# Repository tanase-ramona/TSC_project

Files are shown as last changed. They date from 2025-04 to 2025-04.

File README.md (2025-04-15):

## EBookReader

Am început realizarea proiectului pornind de la schema electrică oferită în enunț. Am adăugat fiecare componentă din biblioteca sugerata și le-am conectat corespunzător, atribuindu-le etichete adecvate. După finalizarea conexiunilor, am rulat o verificare ERC pentru a identifica eventualele erori si am rezolvat marea majoritate. A rămas o singură eroare nerezolvată, deoarece Fusion nu a putut indica locația acesteia. După ce schema a fost finalizată, am trecut la partea de PCB. Am decupat placa conform dimensiunilor cerute folosind masuratorile oferite de Fusion. Cea mai mare provocare a fost identificarea și poziționarea corectă a componentelor pe PGB. După plasare, am realizat rutarea și am validat designul în funcție de regulile specificate în enunț. Pentru a elimina erorile, a fost necesară modificarea footprint-ului pentru anumite piese. În final, am realizat planul de masă atât pentru stratul superior, cât și pentru cel inferior.

## Arhitectură Generală a Sistemului

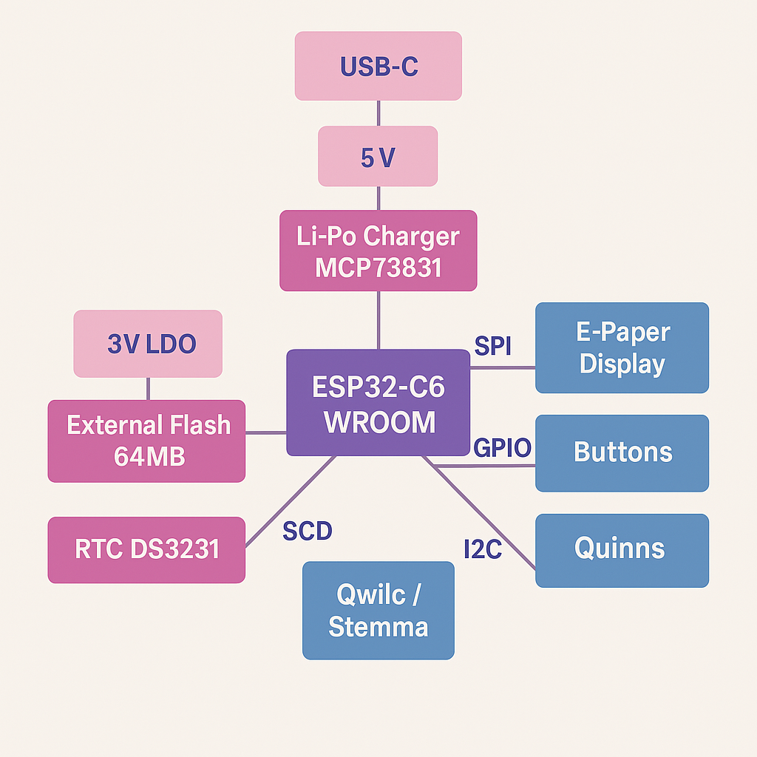
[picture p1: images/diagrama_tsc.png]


## Descriere Generală

Modulul **ESP32-C6-WROOM-1-N8** este nucleul sistemului, facilitând comunicarea cu toate celelalte periferice prin interfețe standard precum I2C, SPI și GPIO. Alimentarea este realizată printr-o baterie Li-Po, gestionată de un controler de încărcare dedicat și monitorizată constant cu ajutorul unui fuel gauge.

## Componente Hardware

###  ESP32-C6
- Microcontroller cu procesor RISC-V
- Conectivitate Wi-Fi 6 și Bluetooth LE
- Interfețe: SPI, I2C, UART, GPIO
- Tensiune de operare: 3.3V

### Componente și resurse

| Componentă  | Link Achiziție | Datasheet |
|---|---|---|
| BOOT_BUTTON | https://ro.mouser.com/ProductDetail/Panasonic/EVQ-P7L01P | https://componentsearchengine.com/Datasheets/2/EVQP7L01P.pdf |
| C1 | https://ro.mouser.com/ProductDetail/YAGEO/CC0402MRX5R5BB106 | https://componentsearchengine.com/Datasheets/2/CC0402MRX5R5BB106.pdf |
| C1_BAT | https://ro.mouser.com/ProductDetail/YAGEO/CC0402MRX5R5BB106 | https://componentsearchengine.com/Datasheets/2/CC0402MRX5R5BB106.pdf |
| C2 | https://ro.mouser.com/ProductDetail/YAGEO/CC0402MRX5R5BB106 | https://componentsearchengine.com/Datasheets/2/CC0402MRX5R5BB106.pdf |
| C2_BAT | https://ro.mouser.com/ProductDetail/YAGEO/CC0402MRX5R5BB106 | https://componentsearchengine.com/Datasheets/2/CC0402MRX5R5BB106.pdf |
| C3 | https://ro.mouser.com/ProductDetail/YAGEO/CC0402MRX5R5BB106 | https://componentsearchengine.com/Datasheets/2/CC0402MRX5R5BB106.pdf |
| C4 | https://ro.mouser.com/ProductDetail/YAGEO/CC0402MRX5R5BB106 | https://componentsearchengine.com/Datasheets/2/CC0402MRX5R5BB106.pdf |
| C4_USB | https://ro.mouser.com/ProductDetail/YAGEO/CC0402MRX5R5BB106 | https://componentsearchengine.com/Datasheets/2/CC0402MRX5R5BB106.pdf |
| C5 | https://ro.mouser.com/ProductDetail/YAGEO/CC0402MRX5R5BB106 | https://componentsearchengine.com/Datasheets/2/CC0402MRX5R5BB106.pdf |
| C5_USB | https://ro.mouser.com/ProductDetail/YAGEO/CC0402MRX5R5BB106 | https://componentsearchengine.com/Datasheets/2/CC0402MRX5R5BB106.pdf |
| C6 | https://ro.mouser.com/ProductDetail/YAGEO/CC0402MRX5R5BB106 | https://componentsearchengine.com/Datasheets/2/CC0402MRX5R5BB106.pdf |
| C7 | https://ro.mouser.com/ProductDetail/YAGEO/CC0402MRX5R5BB106 | https://componentsearchengine.com/Datasheets/2/CC0402MRX5R5BB106.pdf |
| C8 | https://ro.mouser.com/ProductDetail/YAGEO/CC0402MRX5R5BB106 | https://componentsearchengine.com/Datasheets/2/CC0402MRX5R5BB106.pdf |
| C9 | https://ro.mouser.com/ProductDetail/YAGEO/CC0402MRX5R5BB106 | https://componentsearchengine.com/Datasheets/2/CC0402MRX5R5BB106.pdf |
| C10 | https://ro.mouser.com/ProductDetail/YAGEO/CC0402MRX5R5BB106 | https://componentsearchengine.com/Datasheets/2/CC0402MRX5R5BB106.pdf |
| D1 | https://ro.mouser.com/ProductDetail/STMicroelectronics/STPS2L30A | https://www.st.com/resource/en/datasheet/stps2l30.pdf |
| D2 | https://ro.mouser.com/ProductDetail/STMicroelectronics/STPS2L30A | https://www.st.com/resource/en/datasheet/stps2l30.pdf |
| D3 | https://ro.mouser.com/ProductDetail/STMicroelectronics/STPS2L30A | https://www.st.com/resource/en/datasheet/stps2l30.pdf |
| D4 | https://ro.mouser.com/ProductDetail/STMicroelectronics/STPS2L30A | https://www.st.com/resource/en/datasheet/stps2l30.pdf |
| IC1 | https://ro.mouser.com/ProductDetail/Texas-Instruments/BQ24075RGTT | https://www.ti.com/lit/ds/symlink/bq24075.pdf |
| Q1 | https://ro.mouser.com/ProductDetail/Diodes-Incorporated/DMG2305UX-7 | https://www.diodes.com/assets/Datasheets/ds31771.pdf |
| Q2 | https://ro.mouser.com/ProductDetail/Diodes-Incorporated/DMG2305UX-7 | https://www.diodes.com/assets/Datasheets/ds31771.pdf |
| Q3 | https://ro.mouser.com/ProductDetail/Diodes-Incorporated/DMG2305UX-7 | https://www.diodes.com/assets/Datasheets/ds31771.pdf |
| Q4 | https://ro.mouser.com/ProductDetail/Diodes-Incorporated/DMG2305UX-7 | https://www.diodes.com/assets/Datasheets/ds31771.pdf |
| R1 | https://ro.mouser.com/ProductDetail/YAGEO/RC0402FR-0710KL | https://componentsearchengine.com/Datasheets/2/RC0402FR-0710KL.pdf |
| R2 | https://ro.mouser.com/ProductDetail/YAGEO/RC0402FR-0710KL | https://componentsearchengine.com/Datasheets/2/RC0402FR-0710KL.pdf |
| R3 | https://ro.mouser.com/ProductDetail/YAGEO/RC0402FR-0710KL | https://componentsearchengine.com/Datasheets/2/RC0402FR-0710KL.pdf |
| R4 | https://ro.mouser.com/ProductDetail/YAGEO/RC0402FR-0710KL | https://componentsearchengine.com/Datasheets/2/RC0402FR-0710KL.pdf |
| R5 | https://ro.mouser.com/ProductDetail/YAGEO/RC0402FR-07100KL | https://ro.mouser.com/datasheet/2/447/YAGEO_PYu_RC_Group_51_RoHS_L_12-3313492.pdf |
| R6 | https://ro.mouser.com/ProductDetail/YAGEO/RC0402FR-07100KL | https://ro.mouser.com/datasheet/2/447/YAGEO_PYu_RC_Group_51_RoHS_L_12-3313492.pdf |
| R7 | https://ro.mouser.com/ProductDetail/YAGEO/RC0402FR-07100KL | https://ro.mouser.com/datasheet/2/447/YAGEO_PYu_RC_Group_51_RoHS_L_12-3313492.pdf |
| R8 | https://ro.mouser.com/ProductDetail/YAGEO/RC0402FR-07100KL | https://ro.mouser.com/datasheet/2/447/YAGEO_PYu_RC_Group_51_RoHS_L_12-3313492.pdf |
| R9 | https://ro.mouser.com/ProductDetail/YAGEO/RC0402FR-07100KL | https://ro.mouser.com/datasheet/2/447/YAGEO_PYu_RC_Group_51_RoHS_L_12-3313492.pdf |
| R10 | https://ro.mouser.com/ProductDetail/YAGEO/RC0402FR-07100KL | https://ro.mouser.com/datasheet/2/447/YAGEO_PYu_RC_Group_51_RoHS_L_12-3313492.pdf |
| RESET_BUTTON | https://ro.mouser.com/ProductDetail/Panasonic/EVQ-P7L01P | https://componentsearchengine.com/Datasheets/2/EVQP7L01P.pdf |
| R_BOOT | https://ro.mouser.com/ProductDetail/YAGEO/RC0402FR-07100KL | https://ro.mouser.com/datasheet/2/447/YAGEO_PYu_RC_Group_51_RoHS_L_12-3313492.pdf |
| R_CAPACITOR  | https://ro.mouser.com/ProductDetail/YAGEO/RC0402FR-07100KL | https://ro.mouser.com/datasheet/2/447/YAGEO_PYu_RC_Group_51_RoHS_L_12-3313492.pdf |
| R_CHANGE | https://ro.mouser.com/ProductDetail/YAGEO/RC0402FR-07100KL | https://ro.mouser.com/datasheet/2/447/YAGEO_PYu_RC_Group_51_RoHS_L_12-3313492.pdf |
| R_CL1 | https://ro.mouser.com/ProductDetail/YAGEO/RC0402FR-07100KL | https://ro.mouser.com/datasheet/2/447/YAGEO_PYu_RC_Group_51_RoHS_L_12-3313492.pdf |
| R_RESET | https://ro.mouser.com/ProductDetail/YAGEO/RC0402FR-07100KL | https://ro.mouser.com/datasheet/2/447/YAGEO_PYu_RC_Group_51_RoHS_L_12-3313492.pdf |
| SENSOR2 | https://ro.mouser.com/ProductDetail/Bosch-Sensortec/BME680 | https://ro.mouser.com/datasheet/2/783/BST_BME680_DS001-1509608.pdf |
| SJ1 | https://grabcad.com/library/solder-jumpers-1 | https://grabcad.com/library/solder-jumpers-1 |
| U1 | https://ro.mouser.com/ProductDetail/Winbond/W25Q512JVEIQ | https://ro.mouser.com/datasheet/2/949/Winbond_W25Q512JV_Datasheet-3240039.pdf |
| U2 | https://ro.mouser.com/ProductDetail/Espressif-Systems/ESP32-C6-WROOM-1-N8 | https://ro.mouser.com/datasheet/2/891/Espressif_ESP32_C6_WROOM_1__Datasheet_V0_1_PRELIMI-3239987.pdf |
| U3 | https://ro.mouser.com/ProductDetail/Analog-Devices-Maxim-Integrated/DS3231SN | https://ro.mouser.com/datasheet/2/609/DS3231-3421123.pdf |
| U4 | https://ro.mouser.com/ProductDetail/Analog-Devices-Maxim-Integrated/MAX17048G+T10 | https://ro.mouser.com/datasheet/2/609/MAX17048_MAX17049-3469099.pdf |
| U5 | https://ro.mouser.com/ProductDetail/Microchip-Technology/MCP73831T-2ACI-OT | https://ro.mouser.com/datasheet/2/268/MCP73831_Family_Data_Sheet_DS20001984H-3441711.pdf |

###  Sistem de Alimentare
- **MCP73831** – controler de încărcare pentru baterii LiPo
- **MAX17048** – fuel gauge pentru măsurarea nivelului de baterie și avertizare
- **XC6220A331MR** – stabilizator de tensiune 3.3V LDO

###  Protecție și Conectivitate
- Protecție ESD pentru liniile USB (USBLC6)
- Diode Schottky pentru protecție la supratensiune
- Conector USB-C pentru alimentare și comunicație serială

###  Interfață Utilizator
- Buton RESET pentru restart manual
- LED pentru indicarea stării de încărcare

## Estimare Totală Consum în Funcționare Activă:
**~120 – 200 mA** (fără SD Card)

## Estimare Totală în Modul Sleep:
**< 100 µA** (cu ESP32 în deep sleep și periferice oprite)

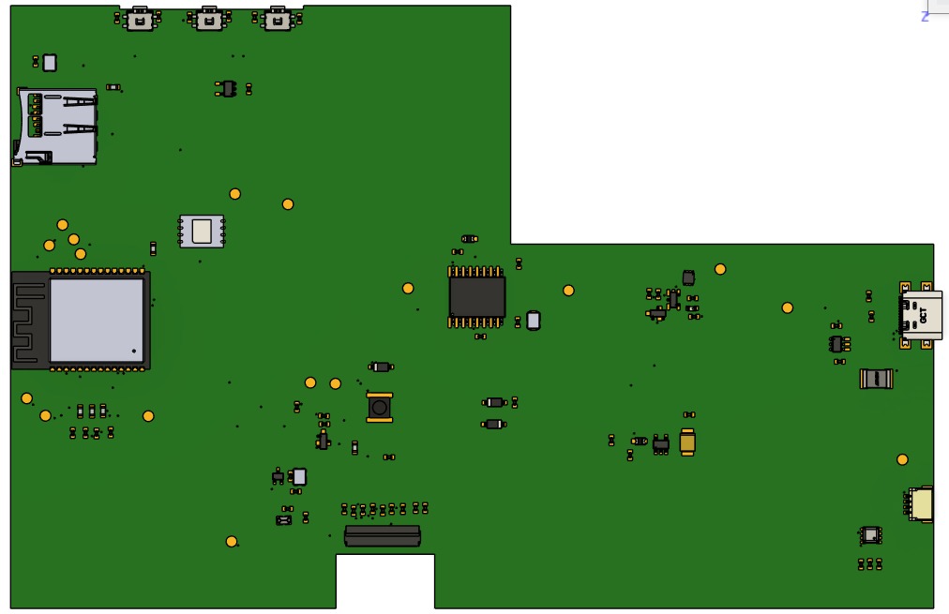
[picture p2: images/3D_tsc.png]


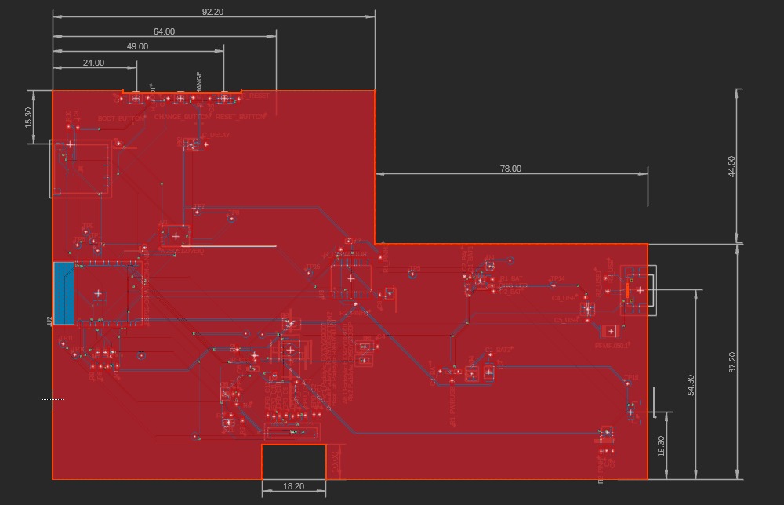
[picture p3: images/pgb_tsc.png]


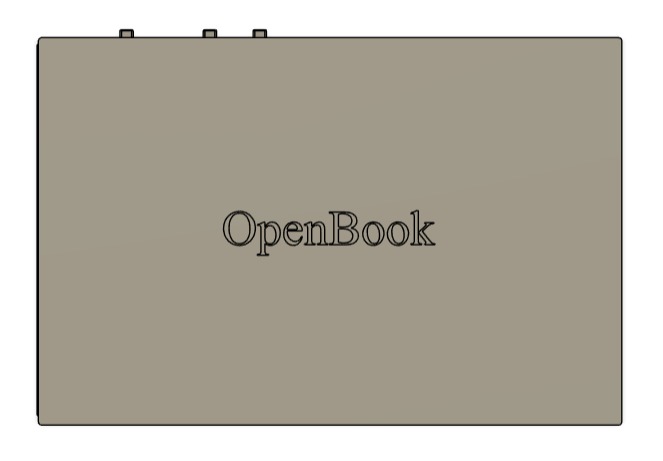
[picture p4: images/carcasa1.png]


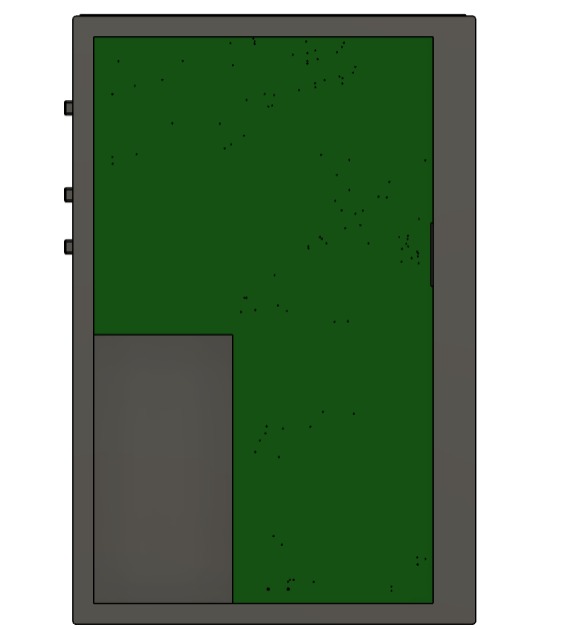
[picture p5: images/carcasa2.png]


---

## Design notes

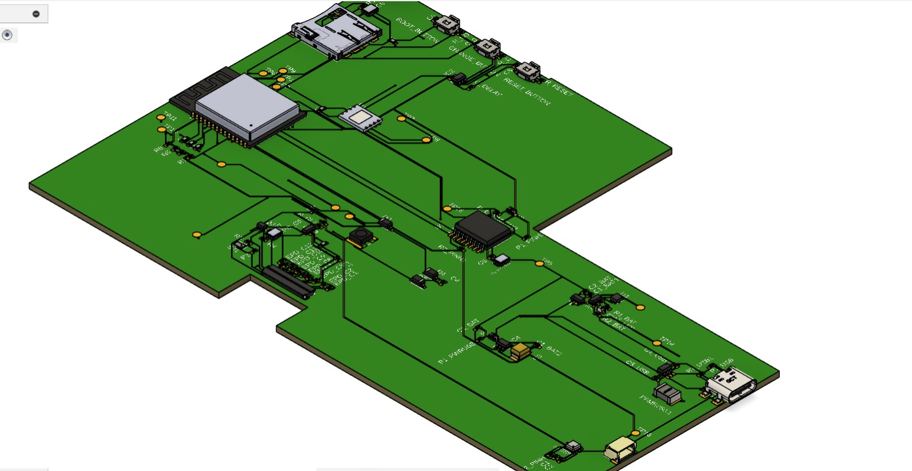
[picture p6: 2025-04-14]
images/3D.png

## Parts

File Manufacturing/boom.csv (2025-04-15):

BOOT_BUTTON | 23.84 | 85.75 | 180.00 | BUTTON_CUSYOMV1 | MYBUTTON
C1 | 158.44 | -15.01 | 270.00 | 100nF | EAGLE-LTSPICE_C0402
C10 | 33.02 | 85.79 | 270.00 | 100nF | EAGLE-LTSPICE_C0402
C10_SUPERCAP | 96.40 | 29.90 | 270.00 | CPH3225A | CAPCP3225X100N
C1_BAT | 110.79 | 7.83 | 270.00 | 4.7uF | EAGLE-LTSPICE_C0402
C1_BAT1 | 119.41 | 34.73 | 90.00 | 4.7uF | EAGLE-LTSPICE_C0402
C1_BAT2 | 125.15 | 12.53 | 180.00 | 4.7uF | EAGLE-LTSPICE_C0402
C2 | 160.12 | -15.04 | 270.00 | 100nF | EAGLE-LTSPICE_C0402
C2_BAT | 117.73 | 34.83 | 88.30 | 4.7uF | EAGLE-LTSPICE_C0402
C3 | 124.82 | 7.45 | 270.00 | 100uF TANT | RCL_CT3528
C4 | 92.95 | 14.79 | 270.00 | 4.7uF/25V | EAGLE-LTSPICE_C0402
C4_USB | 152.27 | 28.91 | 180.00 | 100nF | EAGLE-LTSPICE_C0402
C5 | 45.02 | 85.82 | 270.00 | 1uF | EAGLE-LTSPICE_C0402
C5_USB | 152.88 | 22.31 | 180.00 | 4.7uF | EAGLE-LTSPICE_C0402
C6 | 19.64 | 85.69 | 270.00 | 100nF | EAGLE-LTSPICE_C0402
C7 | 69.80 | 4.69 | 0.00 | 10uF | EAGLE-LTSPICE_C0402
C8 | 93.50 | 29.59 | 90.00 | 100nF | EAGLE-LTSPICE_C0402
C9 | 7.18 | 77.49 | 90.00 | 100nF | EAGLE-LTSPICE_C0402
CHANGE_BUTTON | 36.66 | 85.75 | 180.00 | BUTTON_CUSYOMV1 | MYBUTTON
CHG_LED | 125.67 | 32.15 | 270.00 |  | ADAFRUIT_CHIP-LED0603
C_DELAY | 43.93 | 72.57 | 270.00 | 100nF | EAGLE-LTSPICE_C0402
D1 | 152.95 | 25.53 | 0.00 | USBLC6-2SC6Y | SOT95P280X145-6N
D10 | 17.06 | 13.23 | 90.00 | PGB1010603MR | DIOC1608X36N
D11 | 63.48 | 6.43 | 90.00 | PGB1010603MR | DIOC1608X36N
D12 | 26.30 | 43.13 | 90.00 | PGB1010603MR | DIOC1608X36N
D2 | 115.92 | 7.64 | 180.00 | ESP32_WROVER_AVX---SD0805S020S1R0_AVX_SD0805S020S1R0_0_0AVX_SD0805S020S1R0_0_0 | ESP32_WROVER_AVX---SD0805S020S1R0_AVX_SD0805S020S1R0_0
D3 | 68.31 | 21.34 | 0.00 | MBR0530 | SOD3716X135N
D4 | 89.25 | 14.74 | 0.00 | MBR0530 | SOD3716X135N
D5 | 89.09 | 10.74 | 180.00 | MBR0530 | SOD3716X135N
D6 | 12.85 | 13.14 | 90.00 | PGB1010603MR | DIOC1608X36N
D7 | 84.67 | 44.94 | 0.00 | ESP32_WROVER_AVX---SD0805S020S1R0_AVX_SD0805S020S1R0_0_0AVX_SD0805S020S1R0_0_0 | ESP32_WROVER_AVX---SD0805S020S1R0_AVX_SD0805S020S1R0_0
D8 | 15.03 | 13.14 | 90.00 | PGB1010603MR | DIOC1608X36N
D9 | 18.94 | 72.93 | 0.00 | PGB1010603MR | DIOC1608X36N
EPD_C1 | 76.43 | -4.67 | 90.00 | 1uF/50V | EAGLE-LTSPICE_C0402
EPD_C10 | 64.95 | -5.05 | 90.00 | 1uF/50V | EAGLE-LTSPICE_C0402
EPD_C11 | 63.25 | -5.19 | 90.00 | 1uF/50V | EAGLE-LTSPICE_C0402
EPD_C12 | 61.54 | -4.89 | 90.00 | 1uF/50V | EAGLE-LTSPICE_C0402
EPD_C2 | 74.69 | -4.67 | 270.00 | 1uF/50V | EAGLE-LTSPICE_C0402
EPD_C5 | 72.33 | -4.85 | 90.00 | 0.1uF/50V | EAGLE-LTSPICE_C0402
EPD_C6 | 53.25 | 1.13 | 90.00 | 1uF/50V | EAGLE-LTSPICE_C0402
EPD_C7 | 70.26 | -4.87 | 90.00 | 1uF/50V | EAGLE-LTSPICE_C0402
EPD_C8 | 68.63 | -5.15 | 90.00 | 1uF/50V | EAGLE-LTSPICE_C0402
EPD_C9 | 66.79 | -4.85 | 90.00 | 1uF/50V | EAGLE-LTSPICE_C0402
FH34SRJ-24S-0.5SH_99_1 | 68.58 | -9.65 | 0.00 | FH34SRJ-24S-0.5SH_99_ | FH34SRJ24S05SH99
IC2 | 39.57 | 72.63 | 180.00 | BD5229G-TR | SOT95P280X125-5N
IC4 | 119.91 | 7.03 | 90.00 | XC6220A331MR-G | SOT95P280X120-5N
J1 | 167.16 | -4.01 | 90.00 | QWIIC_RIGHT_ANGLE | JST04_1MM_RA
J2 | 166.63 | 30.86 | 90.00 | SAMACSYS_PARTS_USB4110-GF-A | SAMACSYS_PARTS_USB4110GFA
J4 | 8.28 | 65.61 | 270.00 | 112A-TAAR-R03_ATTEND | 112ATAARR03ATTEND
L1 | 68.03 | 13.85 | 89.90 | 68uH | IND_4828-WE-TPC_WRE
MCP1 | 122.21 | 33.72 | 180.00 | ESP32_WROVER_SPARKFUN-IC-POWER_MCP73831 | ESP32_WROVER_SPARKFUN-IC-POWER_SOT23-5
PFMF.050.1 | 159.63 | 19.14 | 180.00 | ESP32C6_VARISTORCN1812 | ESP32C6_VARISTOR_CT/CN1812
Q1 | 118.61 | 31.21 | 90.00 | 20V/4.2A/52mΩ/1.4W | ESP32_WROVER_SPARKFUN-DISCRETESEMI_SOT23-3
Q2 | 57.68 | 8.36 | 0.00 | 20V/4.2A/52mΩ/1.4W | ESP32_WROVER_SPARKFUN-DISCRETESEMI_SOT23-3
Q3 | 49.32 | 1.24 | 90.00 | SI1308EDL-T1-GE3 | SOT65P210X110-3N
R1 | 18.47 | 9.27 | 90.00 | 10k | ESP32_WROVER_EAGLE-LTSPICE_R0402
R10 | 4.61 | 77.67 | 90.00 | 10K | ESP32_WROVER_EAGLE-LTSPICE_R0402
R1_BAT | 125.76 | 34.01 | 0.00 | 200 | ESP32_WROVER_EAGLE-LTSPICE_R0402
R1_PINH | 57.76 | 12.31 | 356.70 | 10k | ESP32_WROVER_EAGLE-LTSPICE_R0402
R1_PINH1 | 93.71 | 40.35 | 270.00 | 10k | ESP32_WROVER_EAGLE-LTSPICE_R0402
R1_PWRUSB | 114.22 | 5.07 | 90.00 | 100k | ESP32_WROVER_EAGLE-LTSPICE_R0402
R2 | 54.41 | -6.43 | 90.00 | 2.2 | ESP32_WROVER_EAGLE-LTSPICE_R0402
R2_BAT | 126.02 | 30.61 | 180.00 | 2K | ESP32_WROVER_EAGLE-LTSPICE_R0402
R2_PINH | 156.80 | -15.09 | 270.00 | 10k | ESP32_WROVER_EAGLE-LTSPICE_R0402
R2_PINH1 | 86.65 | 26.95 | 179.60 | 10k | ESP32_WROVER_EAGLE-LTSPICE_R0402
R2_USB | 158.23 | 34.39 | 270.00 | 5k1 | ESP32_WROVER_EAGLE-LTSPICE_R0402
R2_USB1 | 158.72 | 30.63 | 270.00 | 5k1 | ESP32_WROVER_EAGLE-LTSPICE_R0402
R3 | 51.09 | -4.83 | 180.00 | 0.47 | ESP32_WROVER_EAGLE-LTSPICE_R0402
R4 | 52.59 | -1.63 | 180.00 | 10k | ESP32_WROVER_EAGLE-LTSPICE_R0402
R5 | 15.85 | 9.07 | 90.00 | 10K | ESP32_WROVER_EAGLE-LTSPICE_R0402
R6 | 13.83 | 9.17 | 90.00 | 10K | ESP32_WROVER_EAGLE-LTSPICE_R0402
R7 | 51.61 | 1.17 | 90.00 | 10K | ESP32_WROVER_EAGLE-LTSPICE_R0402
R8 | 11.47 | 9.17 | 90.00 | 10K | ESP32_WROVER_EAGLE-LTSPICE_R0402
R9 | 52.79 | 13.97 | 90.00 | 10K | ESP32_WROVER_EAGLE-LTSPICE_R0402
RESET_BUTTON | 49.26 | 85.75 | 180.00 | BUTTON_CUSYOMV1 | MYBUTTON
R_BOOT | 27.29 | 85.95 | 270.00 | 10K | ESP32_WROVER_EAGLE-LTSPICE_R0402
R_CAPACITOR | 82.42 | 42.57 | 0.00 | 15 | ESP32_WROVER_EAGLE-LTSPICE_R0402
R_CHANGE | 40.22 | 85.97 | 270.00 | 10K | ESP32_WROVER_EAGLE-LTSPICE_R0402
R_CL1 | 57.86 | 10.79 | 0.00 | 10k | ESP32_WROVER_EAGLE-LTSPICE_R0402
R_RESET | 53.26 | 85.57 | 270.00 | 10K | ESP32_WROVER_EAGLE-LTSPICE_R0402
SENSOR2 | 158.64 | -9.79 | 180.00 | ESP32_WROVER_BME680_BME680 | ESP32_WROVER_BME680_PSON80P300X300X100-8N
SJ1 | 50.38 | -6.95 | 2.20 |  | SJ
TP1 | 11.66 | 44.87 | 0.00 | TPTP20R | TP20R
TP10 | 6.44 | 12.35 | 0.00 | TPTP20R | TP20R
TP11 | 2.99 | 15.55 | 0.00 | TPTP20R | TP20R
TP12 | 40.74 | -10.85 | 0.00 | TPTP20R | TP20R
TP13 | 55.29 | 18.45 | 0.00 | TPTP20R | TP20R
TP14 | 143.24 | 32.25 | 0.00 | TPTP20R | TP20R
TP15 | 73.29 | 35.85 | 0.00 | TPTP20R | TP20R
TP16 | 164.44 | 4.25 | 0.00 | TPTP20R | TP20R
TP17 | 59.89 | 18.25 | 0.00 | TPTP20R | TP20R
TP2 | 12.91 | 42.17 | 0.00 | TPTP20R | TP20R
TP3 | 130.86 | 39.37 | 0.00 | TPTP20R | TP20R
TP4 | 25.41 | 12.27 | 0.00 | TPTP20R | TP20R
TP5 | 102.89 | 35.45 | 0.00 | TPTP20R | TP20R
TP6 | 7.14 | 43.75 | 0.00 | TPTP20R | TP20R
TP7 | 41.39 | 53.25 | 0.00 | TPTP20R | TP20R
TP8 | 51.14 | 51.35 | 0.00 | TPTP20R | TP20R
TP9 | 9.59 | 47.55 | 0.00 | TPTP20R | TP20R
U1 | 35.22 | 46.36 | 0.00 | W25Q512JVEIQ | SON127P600X800X80-9N
U2 | 16.00 | 30.04 | 90.00 | ESP32-C6-WROOM-1-N8 | XCVR_ESP32-C6-WROOM-1-N8
U3 | 85.39 | 34.22 | 90.00 | DS3231SN# | SOIC127P1032X265-16N
U4 | 125.00 | 37.75 | 267.80 | MAX17048G+T10 | SON50P200X200X80-9N

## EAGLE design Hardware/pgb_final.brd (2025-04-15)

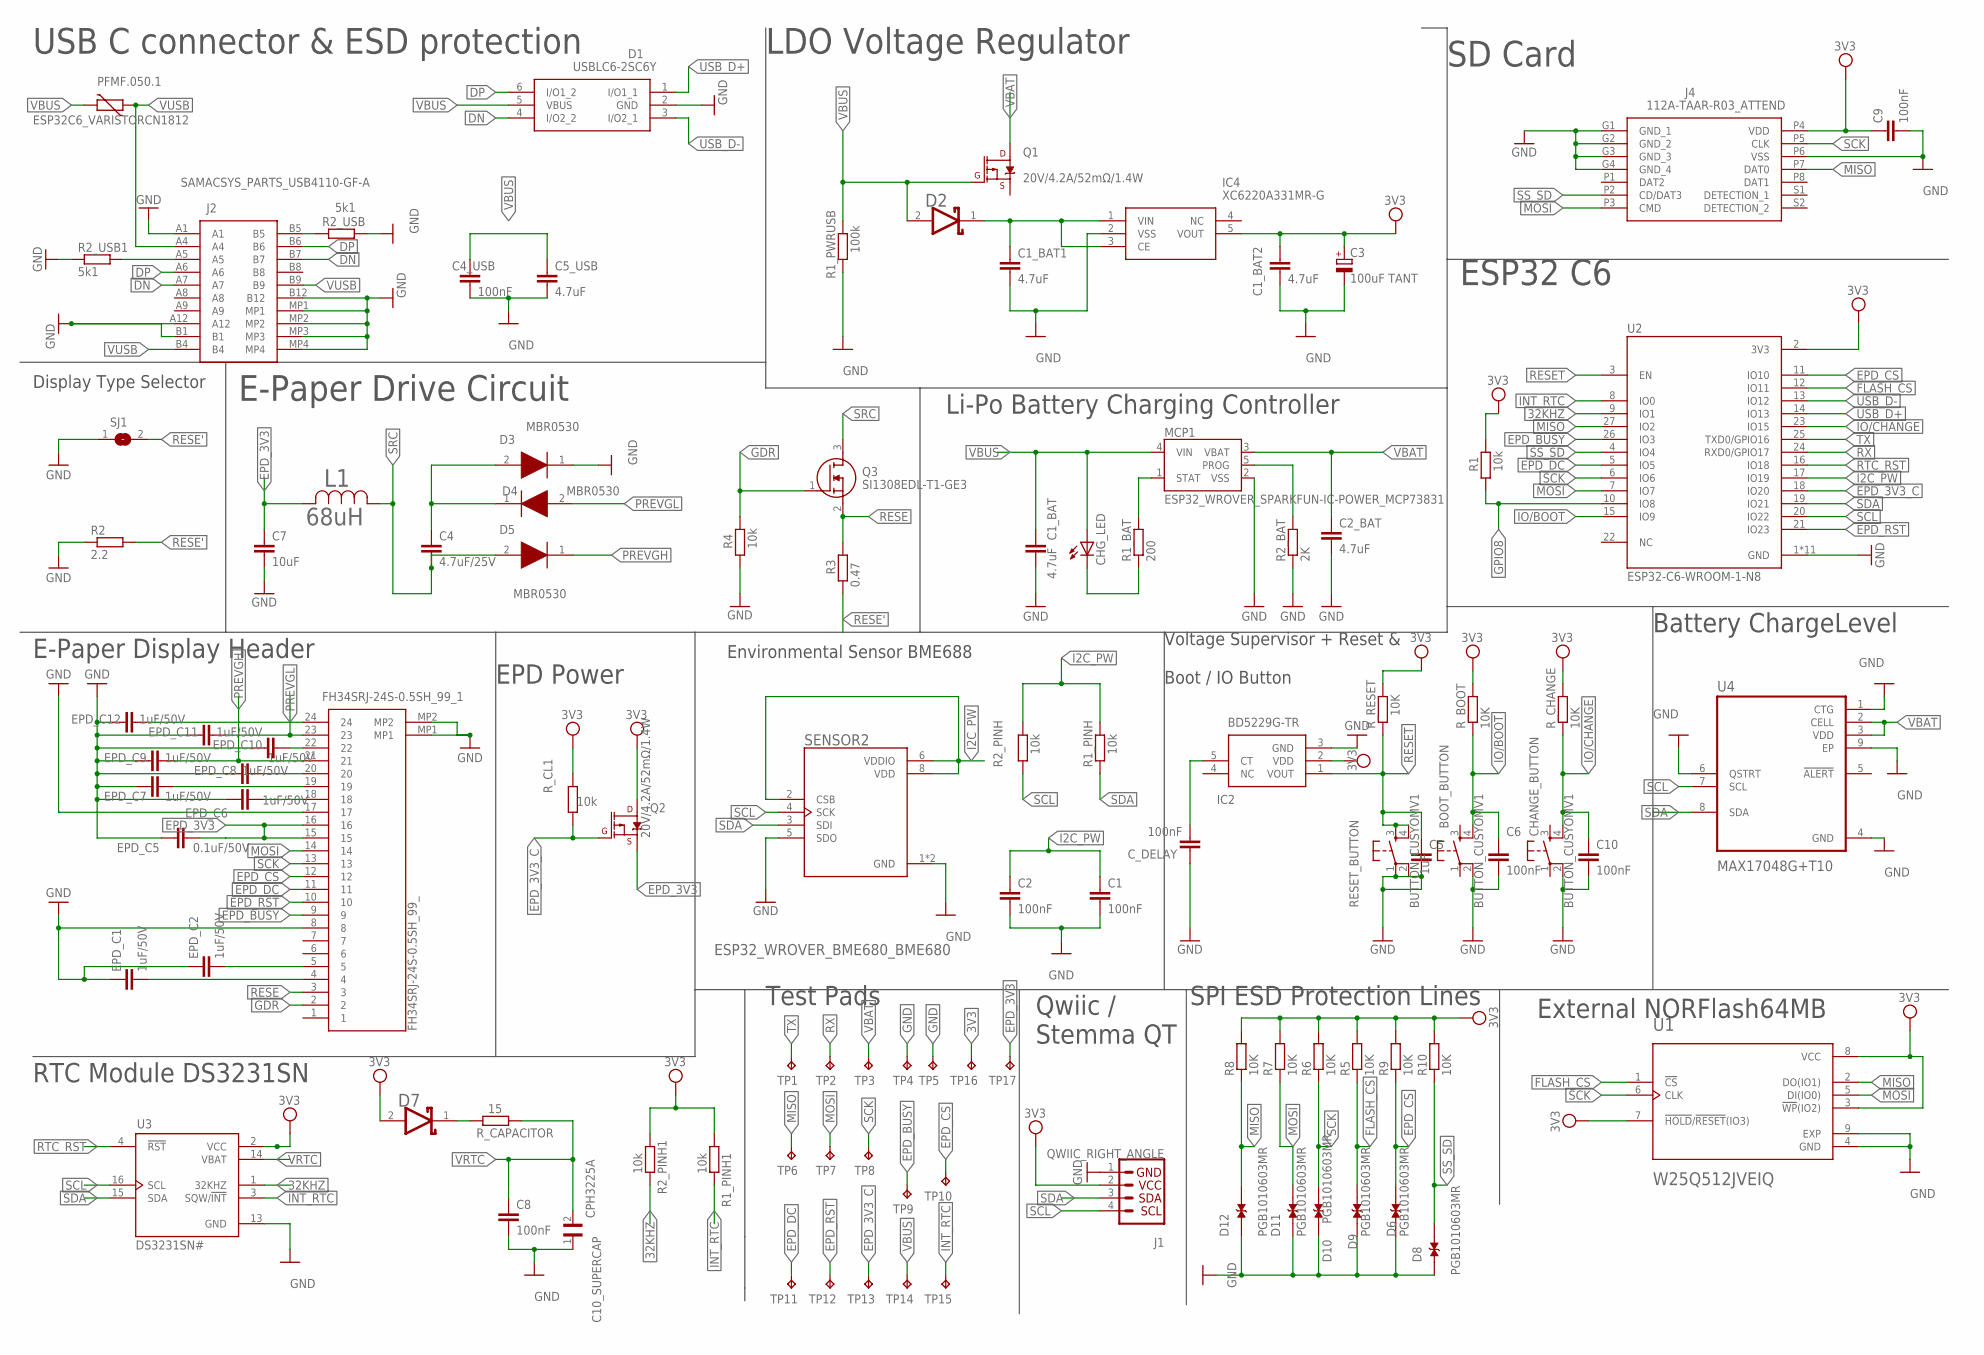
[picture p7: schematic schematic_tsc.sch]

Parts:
BOOT_BUTTON: BUTTON_CUSYOMV1; MYBUTTON
C1, C2, C4_USB, C6, C8, C9, C10: 100nF; EAGLE-LTSPICE_C0402
C1_BAT, C1_BAT1, C1_BAT2, C2_BAT, C5_USB: 4.7uF; EAGLE-LTSPICE_C0402
C3: 100uF TANT; RCL_CT3528
C4: 4.7uF/25V; EAGLE-LTSPICE_C0402
C5: 1uF; EAGLE-LTSPICE_C0402
C7: 10uF; EAGLE-LTSPICE_C0402
C10_SUPERCAP: CPH3225A; CAPCP3225X100N
CHANGE_BUTTON: BUTTON_CUSYOMV1; MYBUTTON
CHG_LED: ADAFRUIT_LEDCHIP-LED0603; ADAFRUIT_CHIP-LED0603
C_DELAY: 100nF; EAGLE-LTSPICE_C0402
D1: USBLC6-2SC6Y; SOT95P280X145-6N
D2, D7: ESP32_WROVER_AVX---SD0805S020S1R0_AVX_SD0805S020S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; ESP32_WROVER_AVX---SD0805S020S1R0_AVX_SD0805S020S1R0_0
D3, D4, D5: MBR0530; SOD3716X135N
D6, D8, D9, D10, D11, D12: PGB1010603MR; DIOC1608X36N
EPD_C1, EPD_C2, EPD_C6, EPD_C7, EPD_C8, EPD_C9, EPD_C10, EPD_C11, EPD_C12: 1uF/50V; EAGLE-LTSPICE_C0402
EPD_C5: 0.1uF/50V; EAGLE-LTSPICE_C0402
FH34SRJ-24S-0.5SH_99_1: FH34SRJ-24S-0.5SH_99_; FH34SRJ24S05SH99
IC2: BD5229G-TR; SOT95P280X125-5N
IC4: XC6220A331MR-G; SOT95P280X120-5N
J1: QWIIC_RIGHT_ANGLE; JST04_1MM_RA
J2: SAMACSYS_PARTS_USB4110-GF-A; SAMACSYS_PARTS_USB4110GFA
J4: 112A-TAAR-R03_ATTEND; 112ATAARR03ATTEND
L1: 68uH; IND_4828-WE-TPC_WRE
MCP1: ESP32_WROVER_SPARKFUN-IC-POWER_MCP73831; ESP32_WROVER_SPARKFUN-IC-POWER_SOT23-5
PFMF.050.1: ESP32C6_VARISTORCN1812; ESP32C6_VARISTOR_CT/CN1812
Q1, Q2: 20V/4.2A/52mΩ/1.4W; ESP32_WROVER_SPARKFUN-DISCRETESEMI_SOT23-3
Q3: SI1308EDL-T1-GE3; SOT65P210X110-3N
R1, R1_PINH, R1_PINH1, R2_PINH, R2_PINH1, R4: 10k; ESP32_WROVER_EAGLE-LTSPICE_R0402
R1_BAT: 200; ESP32_WROVER_EAGLE-LTSPICE_R0402
R1_PWRUSB: 100k; ESP32_WROVER_EAGLE-LTSPICE_R0402
R2: 2.2; ESP32_WROVER_EAGLE-LTSPICE_R0402
R2_BAT: 2K; ESP32_WROVER_EAGLE-LTSPICE_R0402
R2_USB, R2_USB1: 5k1; ESP32_WROVER_EAGLE-LTSPICE_R0402
R3: 0.47; ESP32_WROVER_EAGLE-LTSPICE_R0402
R5, R6, R7, R8, R9, R10: 10K; ESP32_WROVER_EAGLE-LTSPICE_R0402
RESET_BUTTON: BUTTON_CUSYOMV1; MYBUTTON
R_BOOT: 10K; ESP32_WROVER_EAGLE-LTSPICE_R0402
R_CAPACITOR: 15; ESP32_WROVER_EAGLE-LTSPICE_R0402
R_CHANGE: 10K; ESP32_WROVER_EAGLE-LTSPICE_R0402
R_CL1: 10k; ESP32_WROVER_EAGLE-LTSPICE_R0402
R_RESET: 10K; ESP32_WROVER_EAGLE-LTSPICE_R0402
SENSOR2: ESP32_WROVER_BME680_BME680; ESP32_WROVER_BME680_PSON80P300X300X100-8N
SJ1: SJ
TP1, TP2, TP3, TP4, TP5, TP6, TP7, TP8, TP9, TP10, TP11, TP12, TP13, TP14, TP15, TP16, TP17: TPTP20R; TP20R
U1: W25Q512JVEIQ; SON127P600X800X80-9N
U2: ESP32-C6-WROOM-1-N8; XCVR_ESP32-C6-WROOM-1-N8
U3: DS3231SN#; SOIC127P1032X265-16N
U4: MAX17048G+T10; SON50P200X200X80-9N

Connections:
3V3: C1_BAT2.1, C3.+, C9.1, D7.2 (ANODE), IC2.2 (VDD), IC4.5 (VOUT), J1.2, J4.P4 (VDD), Q2.3 (D), R1.2, R1_PINH1.1, R2_PINH1.1, R5.2, R6.2, R7.2, R8.2, R9.2, R10.2, R_BOOT.2, R_CHANGE.2, R_CL1.2, R_RESET.2, TP16.TP, U1.3 (!WP!(IO2)), U1.7 (!HOLD!/!RESET!(IO3)), U1.8 (VCC), U2.2 (3V3), U3.2 (VCC)
32KHZ: R2_PINH1.2, U2.9 (IO1), U3.1 (32KHZ)
DN: D1.4 (I/O2_2), J2.A7, J2.B7
DP: D1.6 (I/O1_2), J2.A6, J2.B6
EPD_3V3: C7.1, EPD_C5.2, FH34SRJ-24S-0.5SH_99_1.15, FH34SRJ-24S-0.5SH_99_1.16, L1.2, Q2.2 (S), TP17.TP
EPD_3V3_C: Q2.1 (G), R_CL1.1, TP13.TP, U2.18 (IO20)
EPD_BUSY: FH34SRJ-24S-0.5SH_99_1.9, TP9.TP, U2.26 (IO3)
EPD_CS: D6.2, FH34SRJ-24S-0.5SH_99_1.12, R9.1, TP10.TP, U2.11 (IO10)
EPD_DC: FH34SRJ-24S-0.5SH_99_1.11, TP11.TP, U2.5 (IO5)
EPD_RST: FH34SRJ-24S-0.5SH_99_1.10, TP12.TP, U2.21 (IO23)
FLASH_CS: D9.2, R5.1, U1.1 (!CS), U2.12 (IO11)
GDR: FH34SRJ-24S-0.5SH_99_1.2, Q3.1 (G), R4.2
GND: BOOT_BUTTON.2, C1.2, C1_BAT.2, C1_BAT1.2, C1_BAT2.2, C2.2, C2_BAT.2, C3.-, C4_USB.2, C5.2, C5_USB.2, C6.2, C7.2, C8.2, C9.2, C10.2, C10_SUPERCAP.1, CHANGE_BUTTON.2, C_DELAY.1, D1.2 (GND), D3.1 (K), D6.1, D8.1, D9.1, D10.1, D11.1, D12.1, EPD_C1.1, EPD_C2.1, EPD_C5.1, EPD_C6.1, EPD_C7.1, EPD_C8.1, EPD_C9.1, EPD_C10.1, EPD_C11.1, EPD_C12.1, FH34SRJ-24S-0.5SH_99_1.8, FH34SRJ-24S-0.5SH_99_1.17, FH34SRJ-24S-0.5SH_99_1.MP1, FH34SRJ-24S-0.5SH_99_1.MP2, IC2.3 (GND), IC4.2 (VSS), J1.1, J2.A1, J2.A12, J2.B1, J2.B12, J2.MP1, J2.MP2, J2.MP3, J2.MP4, J4.G1 (GND_1), J4.G2 (GND_2), J4.G3 (GND_3), J4.G4 (GND_4), J4.P6 (VSS), MCP1.2 (VSS), R1_PWRUSB.1, R2.1, R2_BAT.1, R2_USB.2, R2_USB1.1, R4.1, RESET_BUTTON.1, RESET_BUTTON.2, SENSOR2.1 (GND), SENSOR2.5 (SDO), SENSOR2.7 (GND), SJ1.1, TP4.TP, TP5.TP, U1.4 (GND), U1.9 (EXP), U2.1 (GND), U2.28 (GND), U2.29_1 (GND), U2.29_2 (GND), U2.29_3 (GND), U2.29_4 (GND), U2.29_5 (GND), U2.29_6 (GND), U2.29_7 (GND), U2.29_8 (GND), U2.29_9 (GND), U3.13 (GND), U4.1 (CTG), U4.4 (GND), U4.6 (QSTRT), U4.9 (EP)
GPIO8: R1.1, U2.10 (IO8)
I2C_PW: C1.1, C2.1, R1_PINH.2, R2_PINH.2, SENSOR2.2 (CSB), SENSOR2.6 (VDDIO), SENSOR2.8 (VDD), U2.17 (IO19)
INT_RTC: R1_PINH1.2, TP15.TP, U2.8 (IO0), U3.3 (SQW/!INT)
IO/BOOT: BOOT_BUTTON.4, C6.1, R_BOOT.1, U2.15 (IO9)
IO/CHANGE: C10.1, CHANGE_BUTTON.4, R_CHANGE.1, U2.23 (IO15)
MISO: D12.2, J4.P7 (DAT0), R8.1, TP6.TP, U1.2 (DO(IO1)), U2.27 (IO2)
MOSI: D11.2, FH34SRJ-24S-0.5SH_99_1.14, J4.P3 (CMD), R7.1, TP7.TP, U1.5 (DI(IO0)), U2.7 (IO7)
unnamed: EPD_C10.2, FH34SRJ-24S-0.5SH_99_1.22
unnamed: J2.A5, R2_USB1.2
unnamed: J2.B5, R2_USB.1
unnamed: C1_BAT1.1, D2.1 (CATHODE), IC4.1 (VIN), IC4.3 (CE)
unnamed: C4.1, D3.2 (A), D4.1 (K)
unnamed: MCP1.1 (STAT), R1_BAT.2
unnamed: CHG_LED.C, R1_BAT.1
unnamed: MCP1.5 (PROG), R2_BAT.2
unnamed: EPD_C12.2, FH34SRJ-24S-0.5SH_99_1.24
unnamed: EPD_C8.2, FH34SRJ-24S-0.5SH_99_1.20
unnamed: EPD_C7.2, FH34SRJ-24S-0.5SH_99_1.19
unnamed: EPD_C6.2, FH34SRJ-24S-0.5SH_99_1.18
unnamed: EPD_C2.2, FH34SRJ-24S-0.5SH_99_1.5
unnamed: EPD_C1.2, FH34SRJ-24S-0.5SH_99_1.4
unnamed: C_DELAY.2, IC2.5 (CT)
unnamed: D7.1 (CATHODE), R_CAPACITOR.2
PREVGH: D5.1 (K), EPD_C9.2, FH34SRJ-24S-0.5SH_99_1.21
PREVGL: D4.2 (A), EPD_C11.2, FH34SRJ-24S-0.5SH_99_1.23
RESE: FH34SRJ-24S-0.5SH_99_1.3, Q3.2 (S), R3.2
RESE': R2.2, R3.1, SJ1.2
RESET: C5.1, IC2.1 (VOUT), RESET_BUTTON.3, RESET_BUTTON.4, R_RESET.1, U2.3 (EN)
RTC_RST: U2.16 (IO18), U3.4 (!RST)
RX: TP2.TP, U2.24 (RXD0/GPIO17)
SCK: D10.2, FH34SRJ-24S-0.5SH_99_1.13, J4.P5 (CLK), R6.1, TP8.TP, U1.6 (CLK), U2.6 (IO6)
SCL: J1.4, R2_PINH.1, SENSOR2.4 (SCK), U2.20 (IO22), U3.16 (SCL), U4.7 (SCL)
SDA: J1.3, R1_PINH.1, SENSOR2.3 (SDI), U2.19 (IO21), U3.15 (SDA), U4.8 (SDA)
SRC: C4.2, D5.2 (A), L1.1, Q3.3 (D)
SS_SD: D8.2, J4.P2 (CD/DAT3), R10.1, U2.4 (IO4)
TX: TP1.TP, U2.25 (TXD0/GPIO16)
USB_D+: D1.1 (I/O1_1), U2.14 (IO13)
USB_D-: D1.3 (I/O2_1), U2.13 (IO12)
VBAT: C2_BAT.1, MCP1.3 (VBAT), Q1.3 (D), TP3.TP, U4.2 (CELL), U4.3 (VDD)
VBUS: C1_BAT.1, C4_USB.1, C5_USB.1, CHG_LED.A, D1.5 (VBUS), D2.2 (ANODE), MCP1.4 (VIN), PFMF.050.1.2, Q1.1 (G), R1_PWRUSB.2, TP14.TP
VRTC: C8.1, C10_SUPERCAP.2, R_CAPACITOR.1, U3.14 (VBAT)
VUSB: J2.A4, J2.B4, J2.B9, PFMF.050.1.1

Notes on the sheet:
SD Card
LDO Voltage Regulator
USB C connector & ESD protection
Display Type Selector
E-Paper Drive Circuit
Li-Po Battery Charging Controller
ESP32 C6
E-Paper Display Header
EPD Power
Environmental Sensor BME688
Voltage Supervisor + Reset & Boot / IO Button
Battery ChargeLevel
RTC Module DS3231SN
Test Pads
Qwiic / Stemma QT
SPI ESD Protection Lines
External NORFlash64MB

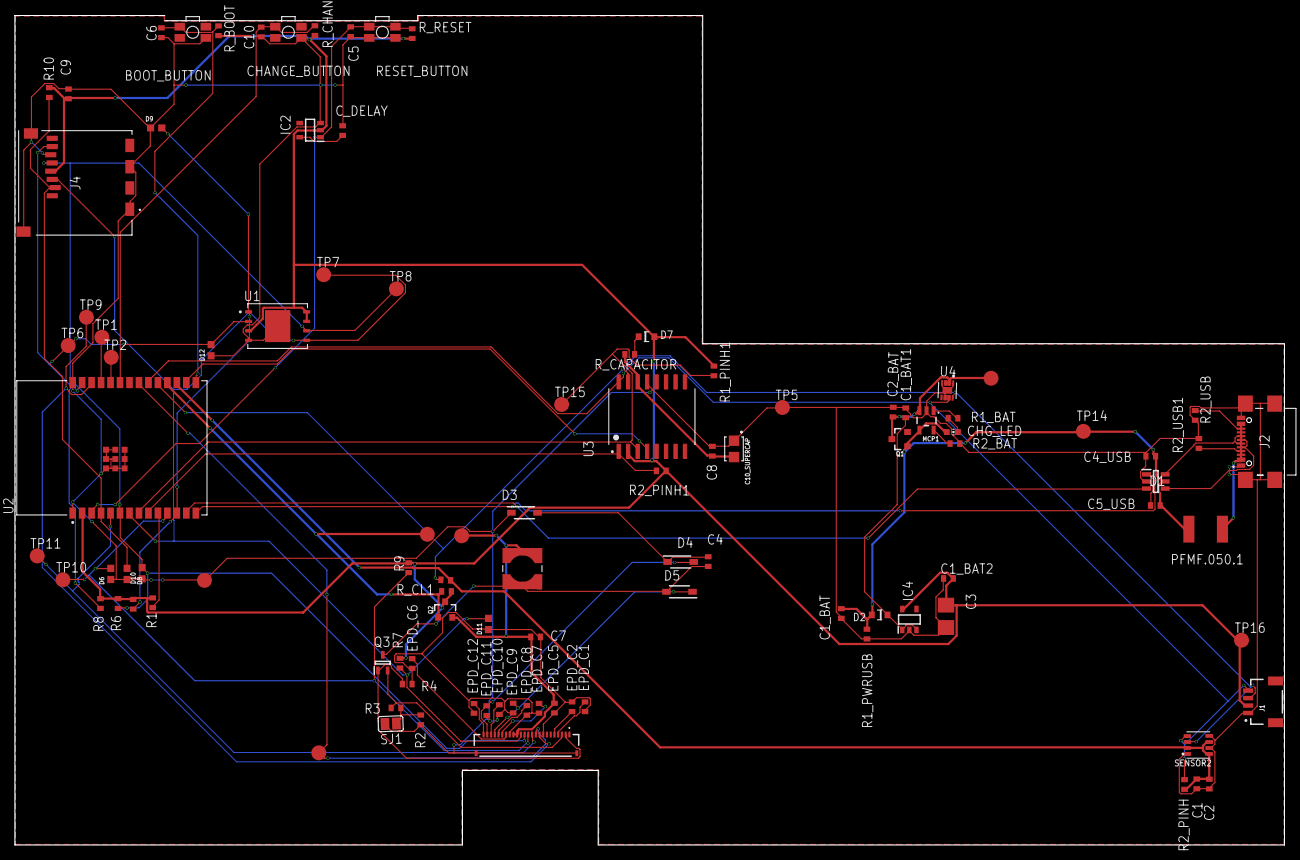
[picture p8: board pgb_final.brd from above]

Board: 2 copper layers, 170.2 x 111.2 mm, 103 parts (0 on the bottom side), 55 nets.

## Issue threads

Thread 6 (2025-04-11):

[PCB] Erori la DRC

lucabotez, 2025-04-11:
5 erori de copper clearance nerezolvate.

Closed 2025-04-16.

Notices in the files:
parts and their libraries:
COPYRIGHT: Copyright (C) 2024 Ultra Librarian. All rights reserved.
